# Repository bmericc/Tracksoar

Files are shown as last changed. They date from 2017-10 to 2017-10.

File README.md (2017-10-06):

# Tracksoar
my Tracksoar repo

Below is the source code for the board and schematic (in <a href="https://www.autodesk.com/products/eagle/overview">EAGLE CAD</a>) and the firmware for the ATMEGA328P running the Arduino bootloader.

Current version (last updated 5/31/2017): Zip file of complete source for Tracksoar:&nbsp;<a href="https://www.tracksoar.com/wp-content/uploads/2015/10/Tracksoar-Source-3.zip">Tracksoar Source</a>

Everything except the ltc3426 boost converter, GPS, Transmitter, and battery terminal can be found in&nbsp;<a href="http://www.mouser.com/ProjectManager/ProjectDetail.aspx?AccessID=907e641ecb">this cart.</a>

LTC3426 can be found&nbsp;<a href="http://www.digikey.com/product-detail/en/linear-technology/LTC3426ES6-TRMPBF/LTC3426ES6-TRMPBFCT-ND/1754255" target="_blank" rel="noopener noreferrer">here.</a>

Battery terminal can be found&nbsp;<a href="http://www.digikey.com/product-detail/en/jst-sales-america-inc/PHR-2/455-1165-ND/608607" target="_blank" rel="noopener noreferrer">here.</a>

The transmitter and GPS can be found&nbsp;<a href="http://ava.upuaut.net/store">here.</a>

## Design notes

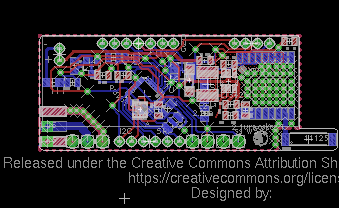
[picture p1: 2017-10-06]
Hardware/TracksoarGerber/Tracksoar.png

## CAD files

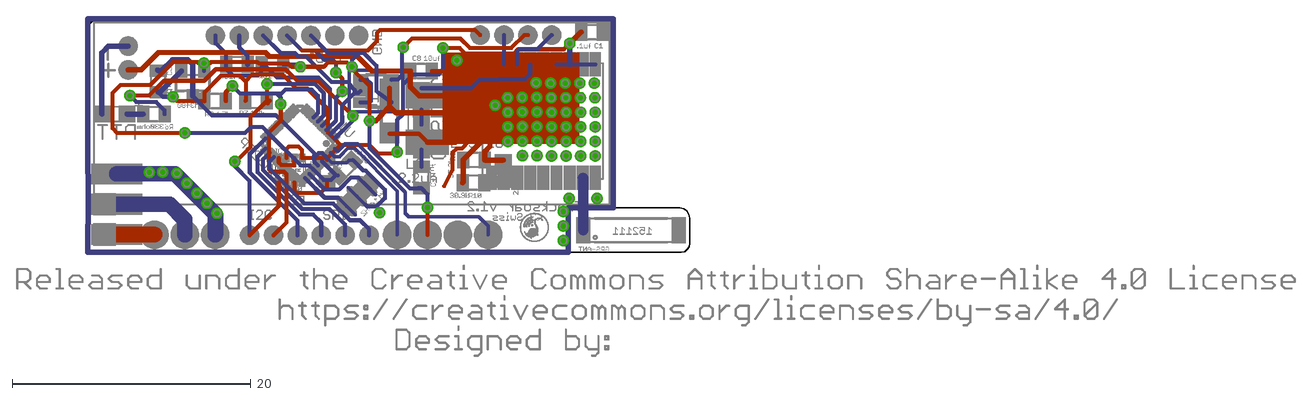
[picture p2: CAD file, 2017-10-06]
Hardware/TracksoarGerber/Tracksoar.dxf
107.1 x 28.5

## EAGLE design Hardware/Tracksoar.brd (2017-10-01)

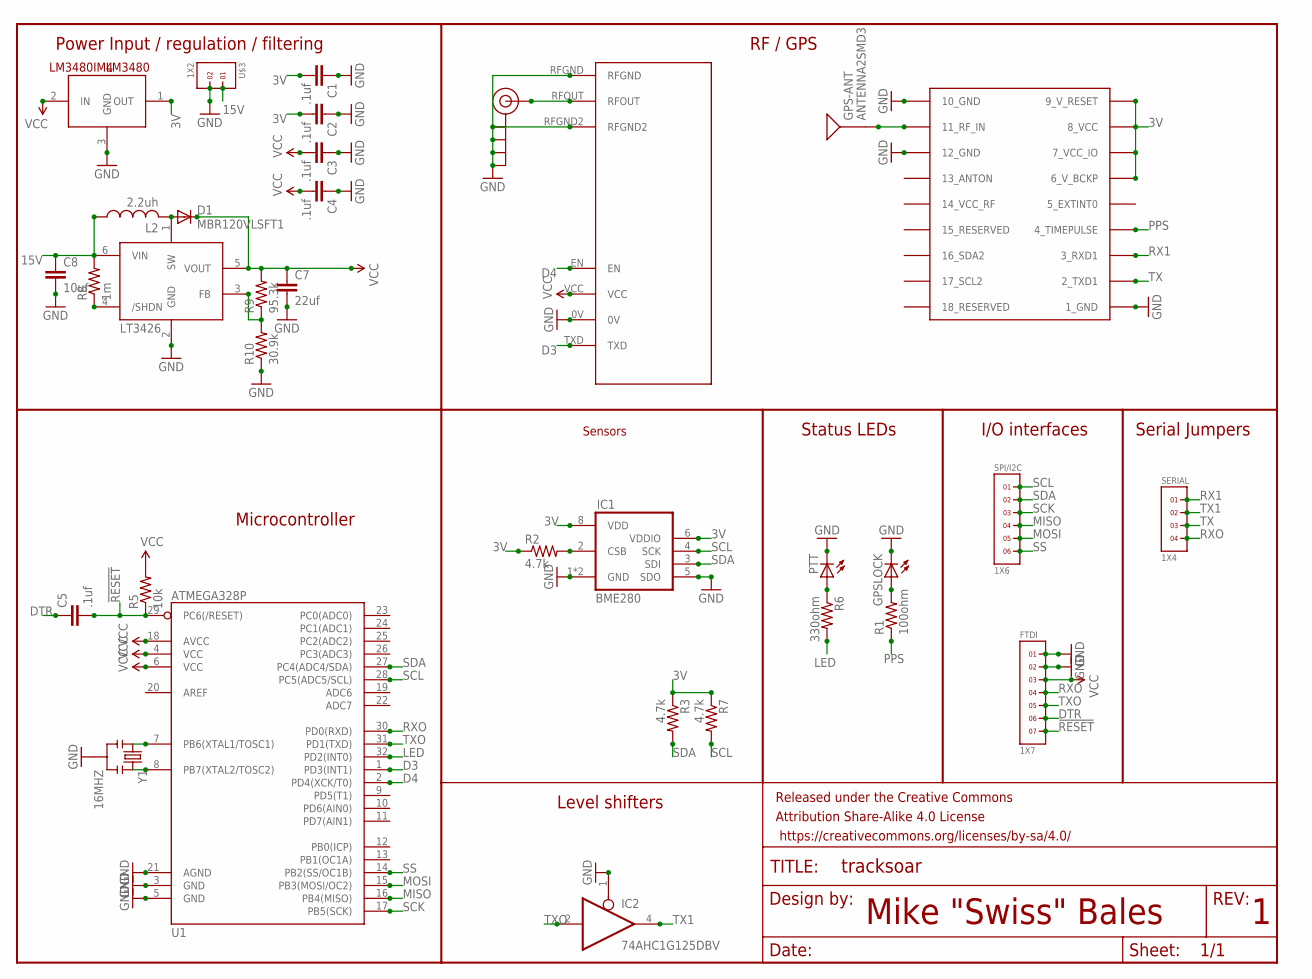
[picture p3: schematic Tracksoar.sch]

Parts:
C1, C2, C3, C4, C5: .1uf; 0805
C7: 22uf; 0805
C8: 10uf; 0805
D1: MBR120VLSFT1; SOD123
FRAME1: FRAME-LETTER; CREATIVE_COMMONS
FTDI: 1X7
GPS-ANT: ANTENNA2SMD3; ANTENNA-CHIP4
GPSLOCK: LEDCHIP-LED0805; CHIP-LED0805
IC1: BME280
IC2: 74AHC1G125DBV; SOT23-5
J$1: SMA_EDGE; SMA-EDGE
L2: 2.2uh; L1812
LM3480: LM3480IM4; SOT23-3
LT3426: LT3426; SOT23-6
PTT: LEDCHIP-LED0805; CHIP-LED0805
R1: 100ohm; 0805
R2, R3, R7: 4.7k; 0805
R5: 10k; 0805
R6: 330ohm; 0805
R8: 1m; 0805
R9: 95.3k; 0805
R10: 30.9k; 0805
SERIAL: 1X4
SPI/I2C: 1X6
U1: ATMEGA328P; MLF32
U$1: UBLOX_MAX
U$2: RADIOMETRIX-HX1
U$3: 1X2
Y1: 16MHZ; RESONATOR-SMD

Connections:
3V: C1.2, C2.2, IC1.6 (VDDIO), IC1.8 (VDD), LM3480.1 (OUT), R2.1, R3.1, R7.1, U$1.6_V_BCKP, U$1.7_VCC_IO, U$1.8_VCC, U$1.9_V_RESET
15V: C8.1, L2.1, LT3426.6 (VIN), R8.2, U$3.1
!RESET: C5.2, FTDI.7, R5.1, U1.29 (PC6(/RESET))
D3: U1.1 (PD3(INT1)), U$2.TXD
D4: U1.2 (PD4(XCK/T0)), U$2.EN
DTR: C5.1, FTDI.6
GND: C1.1, C2.1, C3.1, C4.1, C7.2, C8.2, FTDI.1, FTDI.2, GPSLOCK.C, IC1.1 (GND), IC1.5 (SDO), IC1.7 (GND), IC2.1 (OE), IC2.3 (GND), J$1.GND@0 (GND), J$1.GND@1 (GND), J$1.GND@2 (GND), J$1.GND@3 (GND), LM3480.3 (GND), LT3426.2 (GND), PTT.C, R10.1, U1.3 (GND), U1.5 (GND), U1.21 (AGND), U$1.1_GND, U$1.10_GND, U$1.12_GND, U$2.0V, U$2.RFGND, U$2.RFGND2, U$3.2, Y1.2
LED: R6.2, U1.32 (PD2(INT0))
MISO: SPI/I2C.4, U1.16 (PB4(MISO))
MOSI: SPI/I2C.5, U1.15 (PB3(MOSI/OC2))
unnamed: J$1.SIG (SIGNAL), U$2.RFOUT
unnamed: IC1.2 (CSB), R2.2
unnamed: GPSLOCK.A, R1.2
unnamed: GPS-ANT.SIG, U$1.11_RF_IN
unnamed: D1.A, L2.2, LT3426.1 (SW)
unnamed: LT3426.4 (/SHDN), R8.1
unnamed: LT3426.3 (FB), R9.1, R10.2
unnamed: U1.8 (PB7(XTAL2/TOSC2)), Y1.3
unnamed: U1.7 (PB6(XTAL1/TOSC1)), Y1.1
unnamed: PTT.A, R6.1
PPS: R1.1, U$1.4_TIMEPULSE
RX1: SERIAL.1, U$1.3_RXD1
RXO: FTDI.4, SERIAL.4, U1.30 (PD0(RXD))
SCK: SPI/I2C.3, U1.17 (PB5(SCK))
SCL: IC1.4 (SCK), R7.2, SPI/I2C.1, U1.28 (PC5(ADC5/SCL))
SDA: IC1.3 (SDI), R3.2, SPI/I2C.2, U1.27 (PC4(ADC4/SDA))
SS: SPI/I2C.6, U1.14 (PB2(SS/OC1B))
TX: SERIAL.3, U$1.2_TXD1
TX1: IC2.4 (O), SERIAL.2
TXO: FTDI.5, IC2.2 (I), U1.31 (PD1(TXD))
VCC: C3.2, C4.2, C7.1, D1.C, FTDI.3, IC2.5 (VCC), LM3480.2 (IN), LT3426.5 (VOUT), R5.2, R9.2, U1.4 (VCC), U1.6 (VCC), U1.18 (AVCC), U$2.VCC

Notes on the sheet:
Mike "Swiss" Bales
Power Input / regulation / filtering
RF / GPS
Microcontroller
Level shifters
Status LEDs
I/O interfaces
Serial Jumpers
Sensors

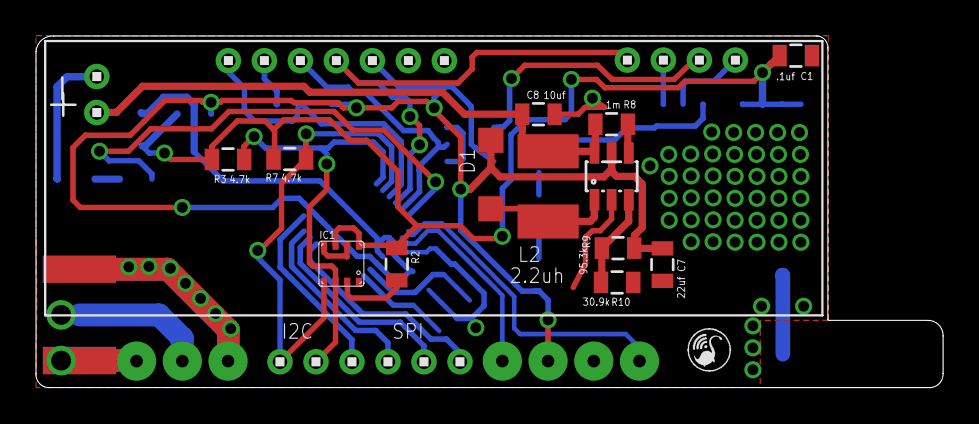
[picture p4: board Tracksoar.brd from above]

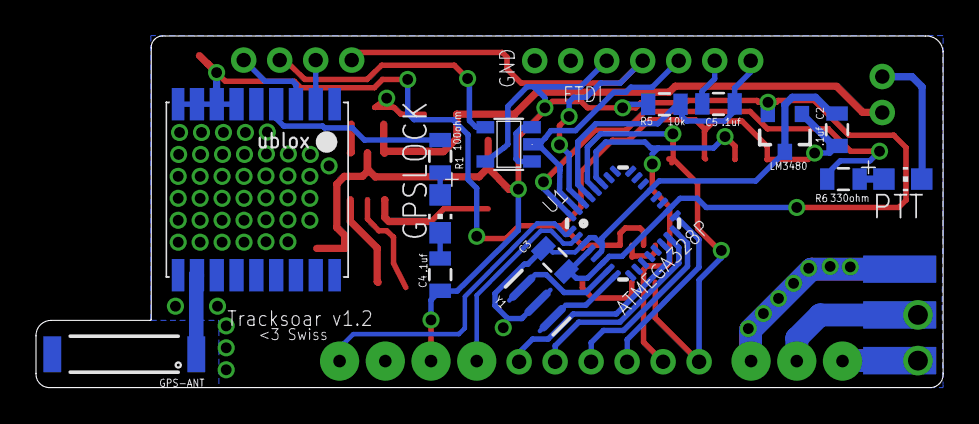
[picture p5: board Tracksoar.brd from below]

Board: 2 copper layers, 50.4 x 19.5 mm, 35 parts (16 on the bottom side), 31 nets.

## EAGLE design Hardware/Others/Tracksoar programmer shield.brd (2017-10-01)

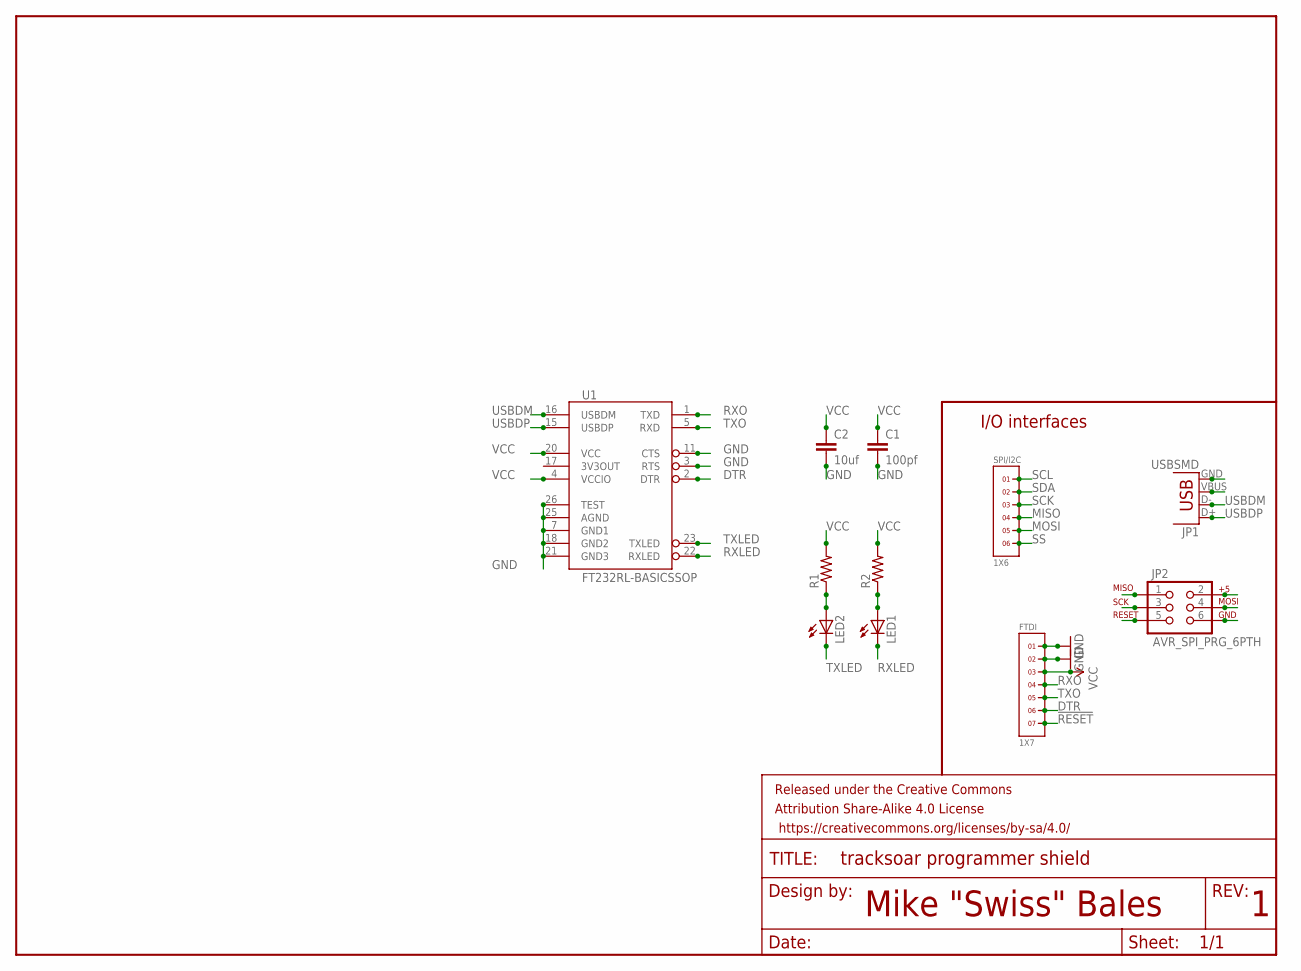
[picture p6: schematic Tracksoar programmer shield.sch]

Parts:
C1: 100pf; 0805
C2: 10uf; 0805
FRAME1: FRAME-LETTER; CREATIVE_COMMONS
FTDI: 1X7
JP1: USBSMD; USB-MINIB
JP2: AVR_SPI_PRG_6PTH; 2X3
LED1, LED2: LEDCHIP-LED0805; CHIP-LED0805
R1, R2: RESISTOR0805-RES; 0805
SPI/I2C: 1X6
U1: FT232RL-BASICSSOP; SSOP28DB

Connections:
!RESET: FTDI.7, JP2.5
DTR: FTDI.6, U1.2 (DTR)
GND: C1.2, C2.2, FTDI.1, FTDI.2, JP1.GND, JP2.6, U1.3 (RTS), U1.7 (GND1), U1.11 (CTS), U1.18 (GND2), U1.21 (GND3), U1.25 (AGND), U1.26 (TEST)
MISO: JP2.1, SPI/I2C.4
MOSI: JP2.4, SPI/I2C.5
unnamed: LED2.A, R1.1
unnamed: LED1.A, R2.1
RXLED: LED1.C, U1.22 (RXLED)
RXO: FTDI.4, U1.1 (TXD)
SCK: JP2.3, SPI/I2C.3
SCL: SPI/I2C.1
SDA: SPI/I2C.2
SS: SPI/I2C.6
TXLED: LED2.C, U1.23 (TXLED)
TXO: FTDI.5, U1.5 (RXD)
USBDM: JP1.D-, U1.16 (USBDM)
USBDP: JP1.D+, U1.15 (USBDP)
VCC: C1.1, C2.1, FTDI.3, JP1.VBUS, JP2.2, R1.2, R2.2, U1.4 (VCCIO), U1.20 (VCC)

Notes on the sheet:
Mike "Swiss" Bales
I/O interfaces

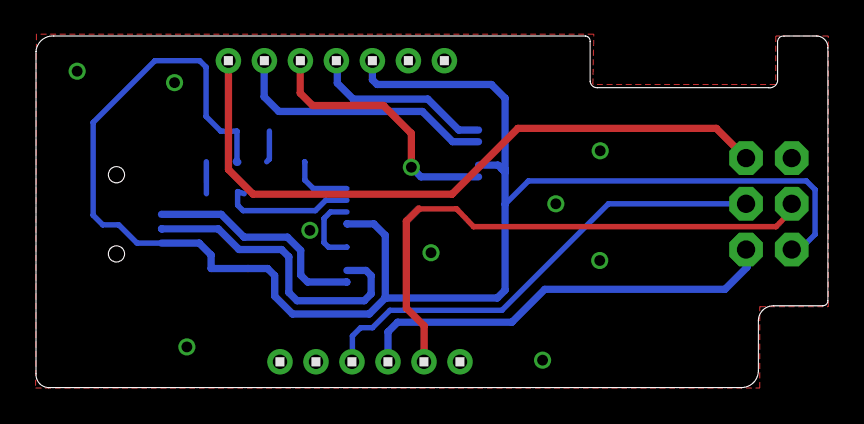
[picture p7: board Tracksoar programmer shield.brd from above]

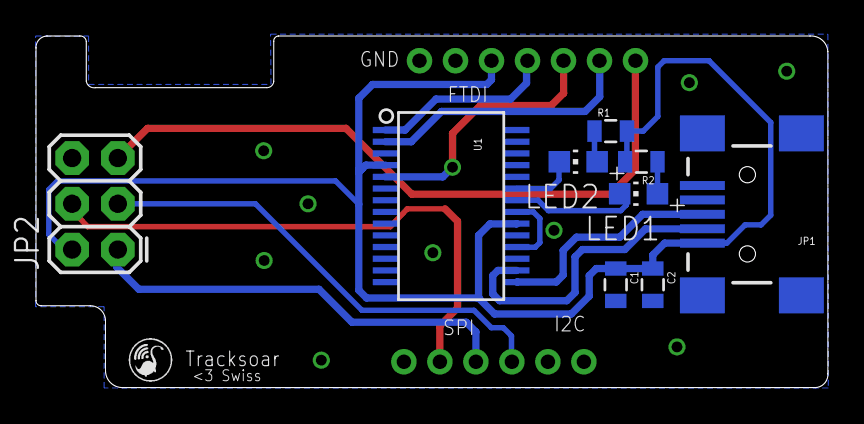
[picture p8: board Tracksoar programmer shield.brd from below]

Board: 2 copper layers, 44.0 x 19.5 mm, 12 parts (9 on the bottom side), 15 nets.

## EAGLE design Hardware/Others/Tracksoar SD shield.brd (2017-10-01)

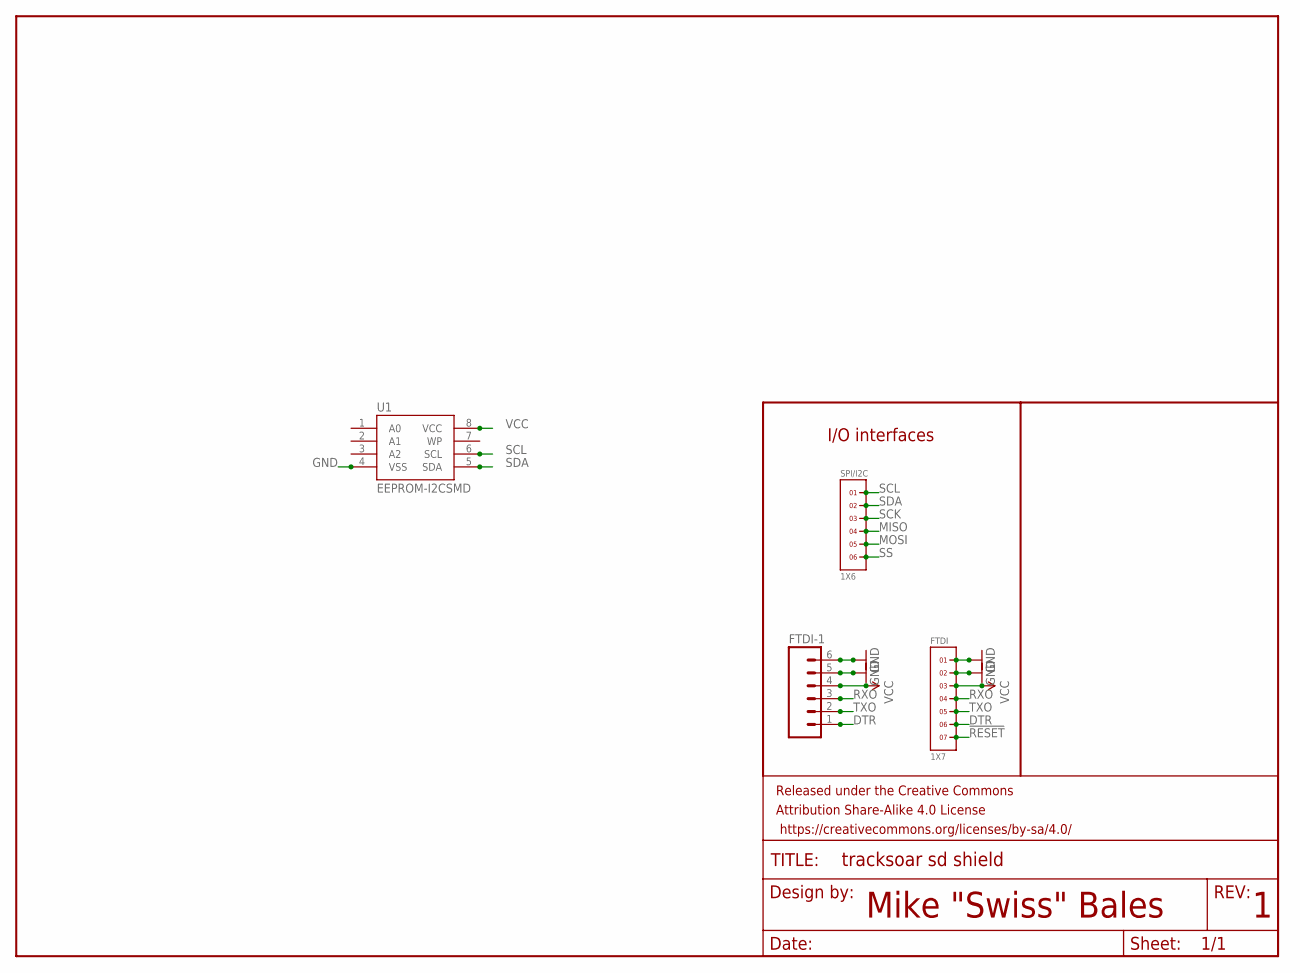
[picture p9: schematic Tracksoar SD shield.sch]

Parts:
FRAME1: FRAME-LETTER; CREATIVE_COMMONS
FTDI: 1X7
FTDI-1: M06LOCK_LONGPADS; 1X06_LOCK_LONGPADS
SPI/I2C: 1X6
U1: EEPROM-I2CSMD; SO08

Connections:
!RESET: FTDI.7
DTR: FTDI.6, FTDI-1.1
GND: FTDI.1, FTDI.2, FTDI-1.5, FTDI-1.6, U1.4 (VSS)
MISO: SPI/I2C.4
MOSI: SPI/I2C.5
RXO: FTDI.4, FTDI-1.3
SCK: SPI/I2C.3
SCL: SPI/I2C.1, U1.6 (SCL)
SDA: SPI/I2C.2, U1.5 (SDA)
SS: SPI/I2C.6
TXO: FTDI.5, FTDI-1.2
VCC: FTDI.3, FTDI-1.4, U1.8 (VCC)

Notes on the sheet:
Mike "Swiss" Bales
I/O interfaces

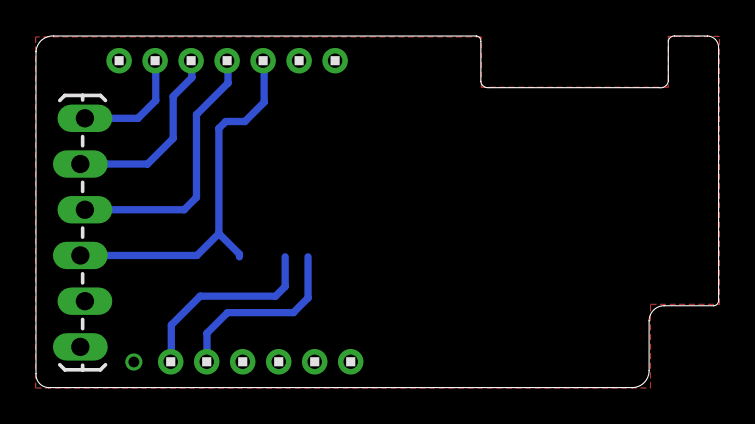
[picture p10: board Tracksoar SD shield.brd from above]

Board: 2 copper layers, 37.9 x 19.5 mm, 5 parts (1 on the bottom side), 7 nets.

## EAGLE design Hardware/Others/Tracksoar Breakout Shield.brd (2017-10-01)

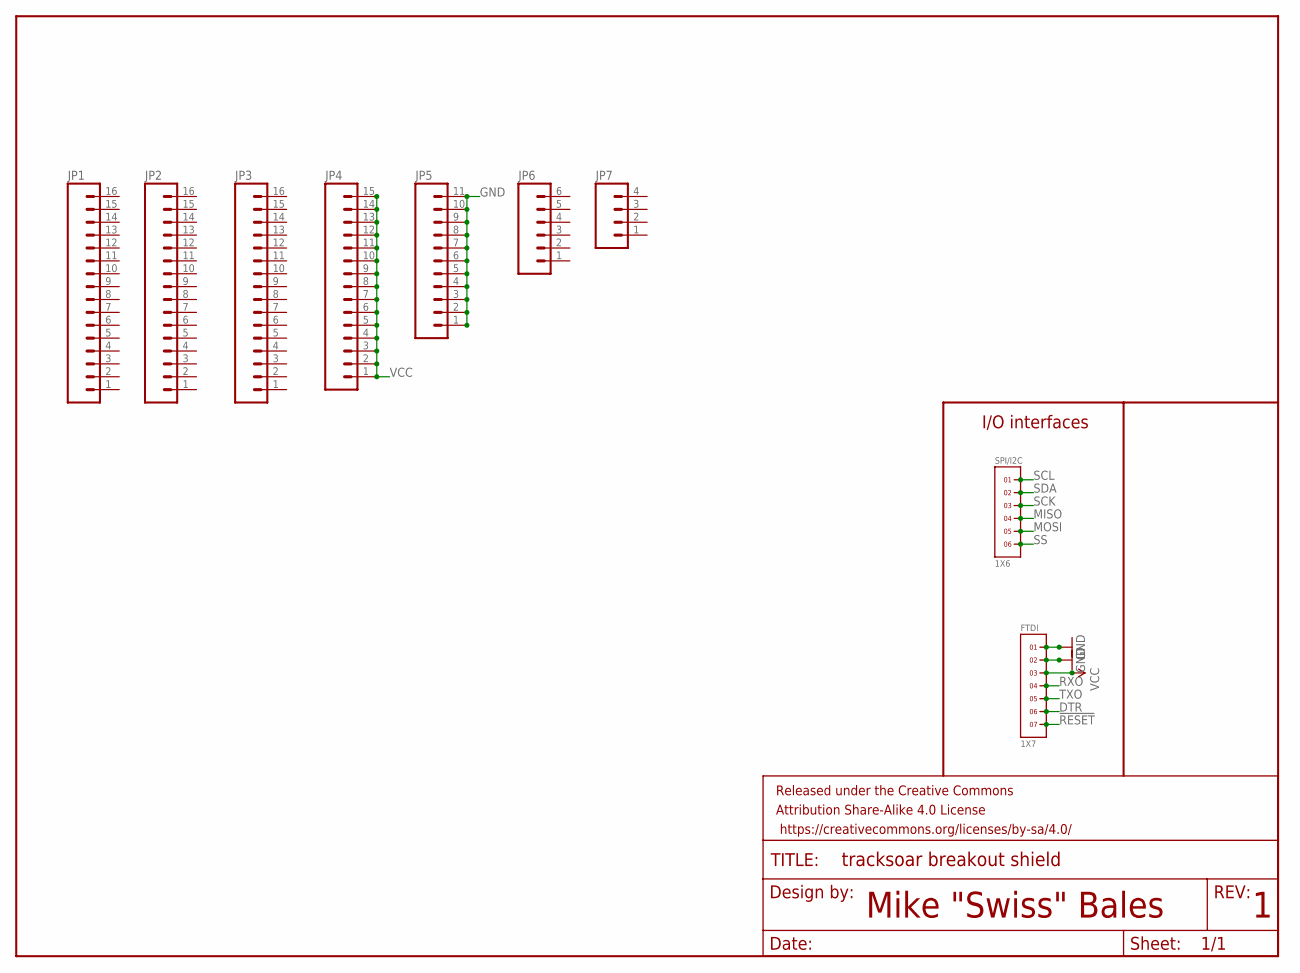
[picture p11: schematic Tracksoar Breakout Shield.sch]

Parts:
FRAME1: FRAME-LETTER; CREATIVE_COMMONS
FTDI: 1X7
JP1, JP2, JP3: M161X16_NO_SILK; 1X16_NO_SILK
JP4: M15; 1X15
JP5: M11PTH; 1X11
JP6: M06NO_SILK_FEMALE_PTH; 1X06_NO_SILK
JP7: M04NO_SILK_ALL_ROUND; 1X04_NO_SILK_ALL_ROUND
SPI/I2C: 1X6

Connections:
!RESET: FTDI.7
DTR: FTDI.6
GND: FTDI.1, FTDI.2, JP5.1, JP5.2, JP5.3, JP5.4, JP5.5, JP5.6, JP5.7, JP5.8, JP5.9, JP5.10, JP5.11
MISO: SPI/I2C.4
MOSI: SPI/I2C.5
RXO: FTDI.4
SCK: SPI/I2C.3
SCL: SPI/I2C.1
SDA: SPI/I2C.2
SS: SPI/I2C.6
TXO: FTDI.5
VCC: FTDI.3, JP4.1, JP4.2, JP4.3, JP4.4, JP4.5, JP4.6, JP4.7, JP4.8, JP4.9, JP4.10, JP4.11, JP4.12, JP4.13, JP4.14, JP4.15

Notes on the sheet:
Mike "Swiss" Bales
I/O interfaces

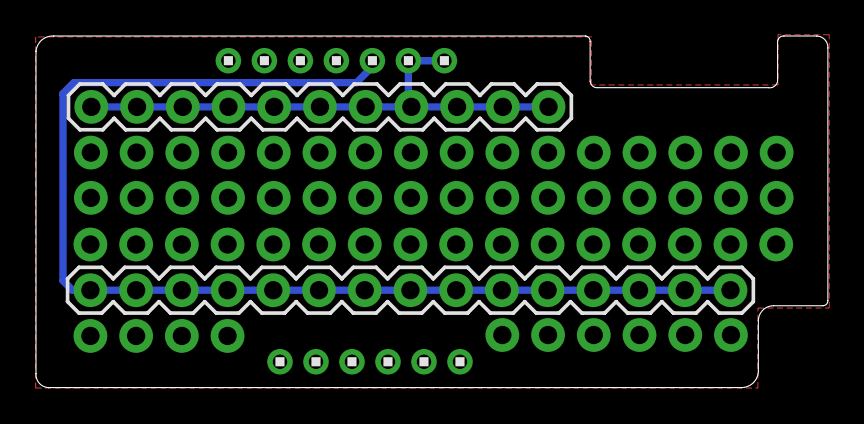
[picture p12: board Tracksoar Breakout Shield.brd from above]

Board: 2 copper layers, 44.0 x 19.5 mm, 10 parts (0 on the bottom side), 2 nets.

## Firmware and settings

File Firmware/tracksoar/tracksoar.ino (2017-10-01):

/* trackuino copyright (C) 2010  EA5HAV Javi
 *
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
 * You should have received a copy of the GNU General Public License
 * along with this program; if not, write to the Free Software
 * Foundation, Inc., 51 Franklin Street, Fifth Floor, Boston, MA  02110-1301, USA.
 */

// Mpide 22 fails to compile Arduino code because it stupidly defines ARDUINO 
// as an empty macro (hence the +0 hack). UNO32 builds are fine. Just use the
// real Arduino IDE for Arduino builds. Optionally complain to the Mpide
// authors to fix the broken macro.
#if (ARDUINO + 0) == 0
#error "Oops! We need the real Arduino IDE (version 22 or 23) for Arduino builds."
#error "See trackuino.pde for details on this"

// Refuse to compile on arduino version 21 or lower. 22 includes an 
// optimization of the USART code that is critical for real-time operation
// of the AVR code.
#elif (ARDUINO + 0) < 22
#error "Oops! We need Arduino 22 or 23"
#error "See trackuino.pde for details on this"

#endif

// Trackuino custom libs
#include "config.h"
#include "afsk_avr.h"
#include "afsk_pic32.h"
#include "aprs.h"
#include "buzzer.h"
#include "gps.h"
#include "pin.h"
#include "power.h"
#include "sensors_avr.h"
#include "sensors_pic32.h"
#include <avr/wdt.h>

// Arduino/AVR libs
#if (ARDUINO + 1) >= 100
#  include <Arduino.h>
#else
#  include <WProgram.h>
#endif
#define cbi(sfr, bit) (_SFR_BYTE(sfr) &= ~_BV(bit))
// Module constants
static const uint32_t VALID_POS_TIMEOUT = 2000;  // ms

// Though not used here, we need to include Wire.h in this file for other code:
#include <Wire.h>
// Same is true for SPI.h
#include <SPI.h>

// Module variables
static int32_t next_aprs = 0;


void setup()
{
  pinMode(LED_PIN, OUTPUT);
  pin_write(LED_PIN, LOW);
  watchdogSetup();
// deactivate internal pull-ups for twi
    // as per note from atmega8 manual pg167
    cbi(PORTC, 4);
    cbi(PORTC, 5);

  Serial.begin(GPS_BAUDRATE);
#ifdef DEBUG_RESET
  Serial.println("RESET");
#endif

  buzzer_setup();
  afsk_setup();
  gps_setup();
  sensors_setup();

#ifdef DEBUG_SENS
  Serial.print("Ti=");
  Serial.print(sensors_int_lm60());
  Serial.print(", Te=");
  Serial.print(sensors_ext_lm60());
  Serial.print(", Vin=");
  Serial.println(sensors_vin());
#endif

  // Do not start until we get a valid time reference
  // for slotted transmissions.
  if (APRS_SLOT >= 0) {
    do {
      while (! Serial.available())
        power_save();
    } while (! gps_decode(Serial.read()));
    
    next_aprs = millis() + 1000 *
      (APRS_PERIOD - (gps_seconds + APRS_PERIOD - APRS_SLOT) % APRS_PERIOD);
  }
  else {
    next_aprs = millis();
  }  
  // TODO: beep while we get a fix, maybe indicating the number of
  // visible satellites by a series of short beeps?
}

void get_pos()
{
  // Get a valid position from the GPS
  int valid_pos = 0;
  uint32_t timeout = millis();
  do {
    if (Serial.available())
      valid_pos = gps_decode(Serial.read());
  } while ( (millis() - timeout < VALID_POS_TIMEOUT) && ! valid_pos) ;

  if (valid_pos) {
    if (gps_altitude > BUZZER_ALTITUDE) {
      buzzer_off();   // In space, no one can hear you buzz
    } else {
      buzzer_on();
    }
  }
}

void loop()
{
  // Time for another APRS frame
  wdt_reset();
  if ((int32_t) (millis() - next_aprs) >= 0) {
    get_pos();
    aprs_send();
    wdt_reset();
    next_aprs += APRS_PERIOD * 1000L;
    while (afsk_flush()) {
      power_save();
      wdt_reset();
    }

#ifdef DEBUG_MODEM
    // Show modem ISR stats from the previous transmission
    afsk_debug();
#endif
  }

  power_save(); // Incoming GPS data or interrupts will wake us up
}

void watchdogSetup(void)
{
 cli();
 wdt_reset();
/*
 WDTCSR configuration:
 WDIE = 1: Interrupt Enable
 WDE = 1 :Reset Enable
 See table for time-out variations:
 WDP3 = 0 :For 1000ms Time-out
 WDP2 = 1 :For 1000ms Time-out
 WDP1 = 1 :For 1000ms Time-out
 WDP0 = 0 :For 1000ms Time-out
*/
// Enter Watchdog Configuration mode:
WDTCSR |= (1<<WDCE) | (1<<WDE);
// Set Watchdog settings:
 WDTCSR = (0<<WDIE) | (1<<WDE) |
(1<<WDP3) | (0<<WDP2) | (0<<WDP1) |
(1<<WDP0);
Serial.println("WDT reset");
sei();
}

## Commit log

2017-10-01 zip to git
    [Tracksoar Breakout Shield.brd, Tracksoar Breakout Shield.sch, Tracksoar SD shield.brd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]
2017-10-06 gerber file
    [Tracksoar Breakout Shield.brd, Tracksoar Breakout Shield.sch, Tracksoar SD shield.brd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]

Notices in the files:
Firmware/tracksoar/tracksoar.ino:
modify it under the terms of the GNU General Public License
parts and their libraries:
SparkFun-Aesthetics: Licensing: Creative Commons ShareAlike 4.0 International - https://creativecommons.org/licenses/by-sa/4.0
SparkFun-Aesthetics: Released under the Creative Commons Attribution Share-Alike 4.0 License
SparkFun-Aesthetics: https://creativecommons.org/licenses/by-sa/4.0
